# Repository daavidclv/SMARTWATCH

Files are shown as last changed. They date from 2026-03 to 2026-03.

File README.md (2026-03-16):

# HWIoT

Esta rama incluye el contenido relacionado con la electrónica del proytecto como esquemas eléctricos, componentes, etc

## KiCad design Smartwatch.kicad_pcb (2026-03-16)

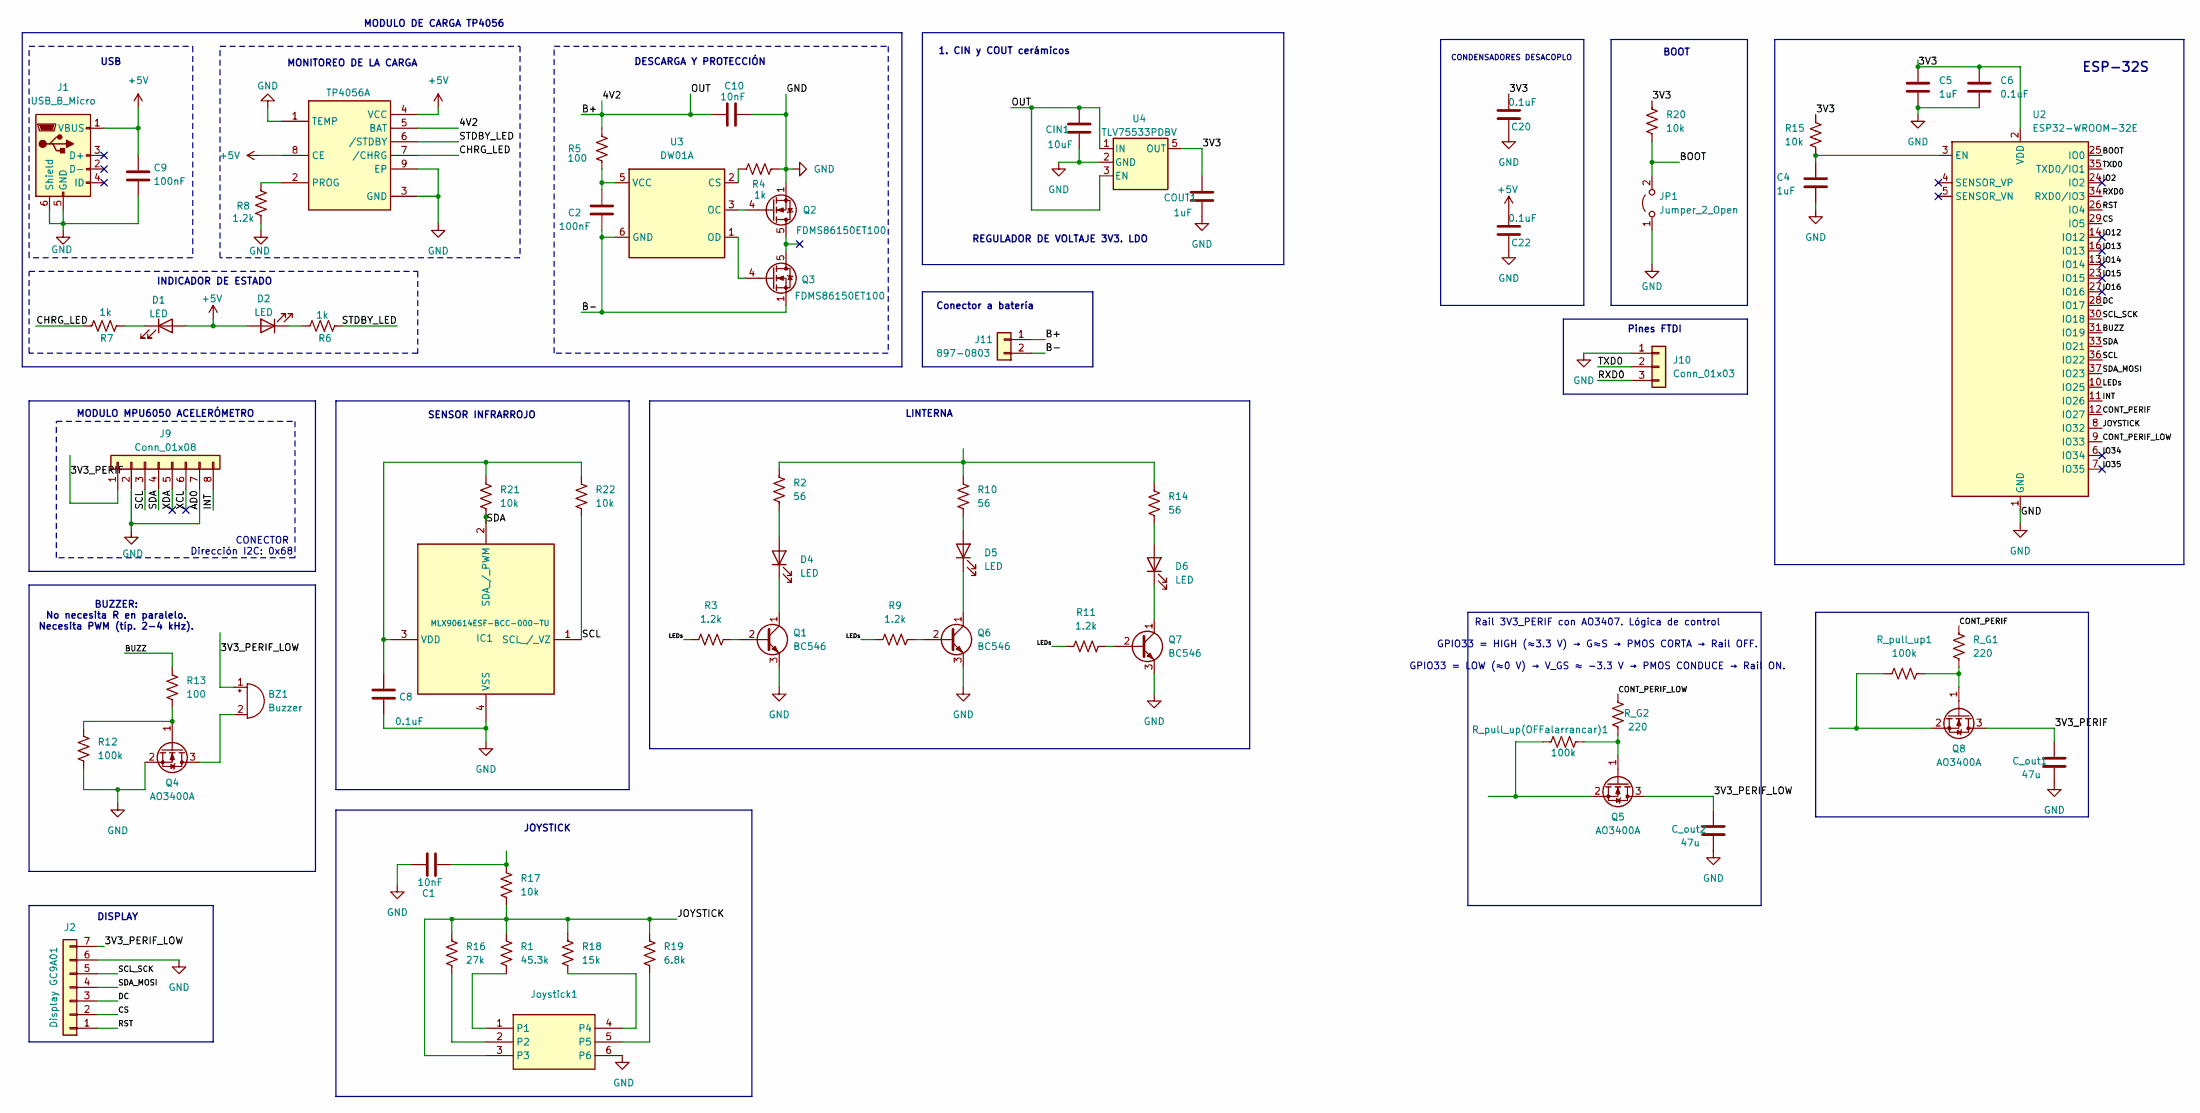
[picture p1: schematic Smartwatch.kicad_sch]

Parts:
BZ1: Buzzer; Buzzer_15x7.5RM7.6
C1, C10: 10nF; C_0805_2012Metric
C2, C9: 100nF; C_0805_2012Metric
C4, C5: 1uF; C_0805_2012Metric
C6, C8, C20, C22: 0.1uF; C_0805_2012Metric
CIN1: 10uF; CP_Radial_D4.0mm_P2.00mm
COUT1: 1uF; CP_Radial_D4.0mm_P2.00mm
C_out1, C_out2: 47u; C_0805_2012Metric
D1, D2, D4, D5, D6: LED; LED_D3.0mm
IC1: MLX90614ESF-BCC-000-TU; MLX90614ESFBCC000TU; Mouser Part Number 482-90614ESFBCC000TU
J1: USB_B_Micro; USB_Mini-B_Wuerth_65100516121_Horizontal
J2: Display GC9A01; PinHeader_1x07_P2.54mm_Vertical
J9: Conn_01x08; PinHeader_1x08_P2.54mm_Vertical
J10: Conn_01x03; PinHeader_1x03_P2.54mm_Vertical
J11: 897-0803; JST_XH_S2B-XH-A_1x02_P2.50mm_Horizontal
JP1: Jumper_2_Open; PinHeader_1x02_P2.54mm_Vertical
Joystick1: Joystick
Q1, Q6, Q7: BC546; TO-92_Inline
Q2, Q3: FDMS86150ET100; TDSON-8-1
Q4, Q5, Q8: AO3400A; SOT-23
R1: 45.3k; R_0805_2012Metric
R2, R10, R14: 56; R_0805_2012Metric
R3, R8, R9, R11: 1.2k; R_0805_2012Metric
R4, R6, R7: 1k; R_0805_2012Metric
R5, R13: 100; R_0805_2012Metric
R12: 100k; R_0805_2012Metric
R15, R17, R20, R21, R22: 10k; R_0805_2012Metric
R16: 27k; R_0805_2012Metric
R18: 15k; R_0805_2012Metric
R19: 6.8k; R_0805_2012Metric
R_G1, R_G2: 220; R_0805_2012Metric
R_pull_up1: 100k; R_0805_2012Metric
R_pull_up(OFFalarrancar)1: 100k; R_0805_2012Metric
TP4056: 4538; TP4056-42-ESOP8_TPW
U2: ESP32-WROOM-32E; ESP32-WROOM-32D
U3: DW01A; SOT-23-6
U4: TLV75533PDBV; SOT-23-5

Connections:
+5V: C9.1, C22.1, D1.2 (A), D2.2 (A), J1.1 (VBUS), TP4056.4 (VCC), TP4056.8 (CE)
/3V3: C5.1, C6.1, C20.1, COUT1.1, R15.1, R20.1, U2.2 (VDD), U4.5 (OUT)
/3V3_PERIF: C_out1.1, J9.1, Q8.3 (D)
/3V3_PERIF_LOW: BZ1.1 (+), C_out2.1, J2.7, Q5.3 (D)
/4V2: C10.1, CIN1.1, J11.1 (Puente1), R5.2, TP4056.5 (BAT), U4.1 (IN), U4.3 (EN)
/B-: C2.1, J11.2 (Puente2), Q3.1 (S), Q3.2 (S), Q3.3 (S), U3.6 (GND)
/BOOT: JP1.2 (B), R20.2, U2.25 (IO0)
/BUZZ: R13.2, U2.31 (IO19)
/CHRG_LED: R7.2, TP4056.7 (/CHRG)
/CONT_PERIF: R_G1.2, U2.12 (IO27)
/CONT_PERIF_LOW: R_G2.2, U2.9 (IO33)
/CS: J2.2, U2.29 (IO5)
/DC: J2.3, U2.28 (IO17)
/INT: J9.8, U2.11 (IO26)
/IO2: U2.24 (IO2)
/IO12: U2.14 (IO12)
/IO13: U2.16 (IO13)
/IO14: U2.13 (IO14)
/IO15: U2.23 (IO15)
/IO16: U2.27 (IO16)
/IO34: U2.6 (IO34)
/IO35: U2.7 (IO35)
/JOYSTICK: Joystick1.3, R1.1, R16.2, R17.1, R18.2, R19.2, U2.8 (IO32)
/LEDs: R3.1, R9.1, R11.1, U2.10 (IO25)
/RST: J2.1, U2.26 (IO4)
/RXD0: J10.3, U2.34 (RXD0/IO3)
/SCL: IC1.1 (SCL_/_VZ), J9.3, R22.2, U2.36 (IO22)
/SCL_SCK: J2.5, U2.30 (IO18)
/SDA: IC1.2 (SDA_/_PWM), J9.4, R21.1, U2.33 (IO21)
/SDA_MOSI: J2.4, U2.37 (IO23)
/STDBY_LED: R6.1, TP4056.6 (/STDBY)
/TXD0: J10.2, U2.35 (TXD0/IO1)
/XCL: J9.6
/XDA: J9.5
GND: C1.2, C4.2, C5.2, C6.2, C8.2, C9.2, C10.2, C20.2, C22.2, CIN1.2, COUT1.2, C_out1.2, C_out2.2, IC1.4 (VSS), J1.5 (GND), J1.6 (Shield), J2.6, J9.2, J9.7, J10.1, JP1.1 (A), Joystick1.6, Q1.3 (E), Q2.1 (S), Q2.2 (S), Q2.3 (S), Q4.2 (S), Q6.3 (E), Q7.3 (E), R4.2, R8.1, R12.1, TP4056.1 (TEMP), TP4056.3 (GND), TP4056.9 (EP), U2.1 (GND), U2.15 (GND), U2.38 (GND), U2.39 (GND), U4.2 (GND)
unnamed: BZ1.2 (-), Q4.3 (D)
unnamed: C1.1, R17.2
unnamed: D1.1 (K), R7.1
unnamed: D2.1 (K), R6.2
unnamed: D4.2 (A), R2.2
unnamed: D4.1 (K), Q1.1 (C)
unnamed: D5.2 (A), R10.2
unnamed: D5.1 (K), Q6.1 (C)
unnamed: D6.2 (A), R14.2
unnamed: D6.1 (K), Q7.1 (C)
unnamed: C8.1, IC1.3 (VDD), R21.2, R22.1
unnamed: Joystick1.1, R1.2
unnamed: Joystick1.2, R16.1
unnamed: Joystick1.4, R18.1
unnamed: Joystick1.5, R19.1
unnamed: Q1.2 (B), R3.2
unnamed: Q2.4 (G), U3.3 (OC)
unnamed: Q3.4 (G), U3.1 (OD)
unnamed: Q4.1 (G), R12.2, R13.1
unnamed 54: Q5.1 (G), R_G2.1, R_pull_up(OFFalarrancar)1.2; also elsewhere on the board
unnamed 55: Q5.2 (S), R_pull_up(OFFalarrancar)1.1; also elsewhere on the board
unnamed: Q6.2 (B), R9.2
unnamed: Q7.2 (B), R11.2
unnamed 58: Q8.1 (G), R_G1.1, R_pull_up1.2; also elsewhere on the board
unnamed 59: Q8.2 (S), R_pull_up1.1; also elsewhere on the board
unnamed: R2.1, R10.1, R14.1
unnamed: R8.2, TP4056.2 (PROG)
unnamed: C4.1, R15.2, U2.3 (EN)
unnamed: R4.1, U3.2 (CS)
unnamed: C2.2, R5.1, U3.5 (VCC)

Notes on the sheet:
CONECTOR
MODULO MPU6050 ACELERÓMETRO
DESCARGA Y PROTECCIÓN
USB
CONDENSADORES DESACOPLO
ESP-32S
Pines FTDI
SENSOR INFRARROJO
REGULADOR DE VOLTAJE 3V3. LDO
MODULO DE CARGA TP4056
Dirección I2C: 0x68
1. CIN y COUT cerámicos
LINTERNA
JOYSTICK
BUZZER: No necesita R en paralelo. Necesita PWM (típ. 2-4 kHz).
MONITOREO DE LA CARGA
DISPLAY
Rail 3V3_PERIF con AO3407. Lógica de control GPIO33 = HIGH (≈3.3 V) → G≈S → PMOS CORTA → Rail OFF. GPIO33 = LOW (≈0 V) → V_GS ≈ −3.3 V → PMOS CONDUCE → Rail ON.
Conector a batería
INDICADOR DE ESTADO
BOOT

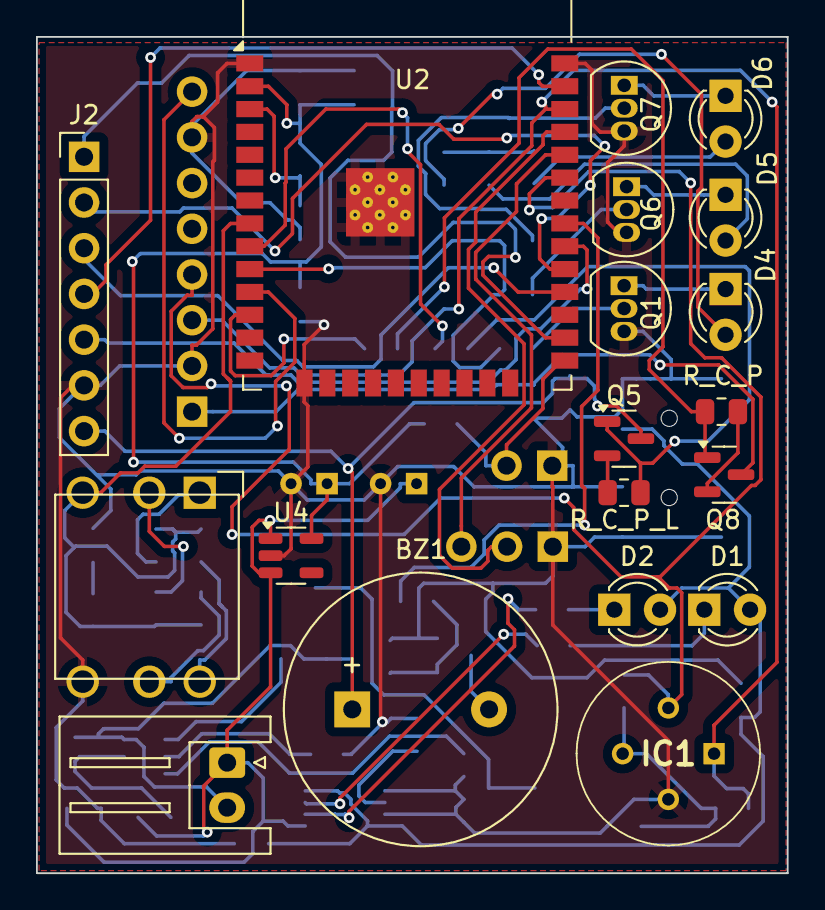
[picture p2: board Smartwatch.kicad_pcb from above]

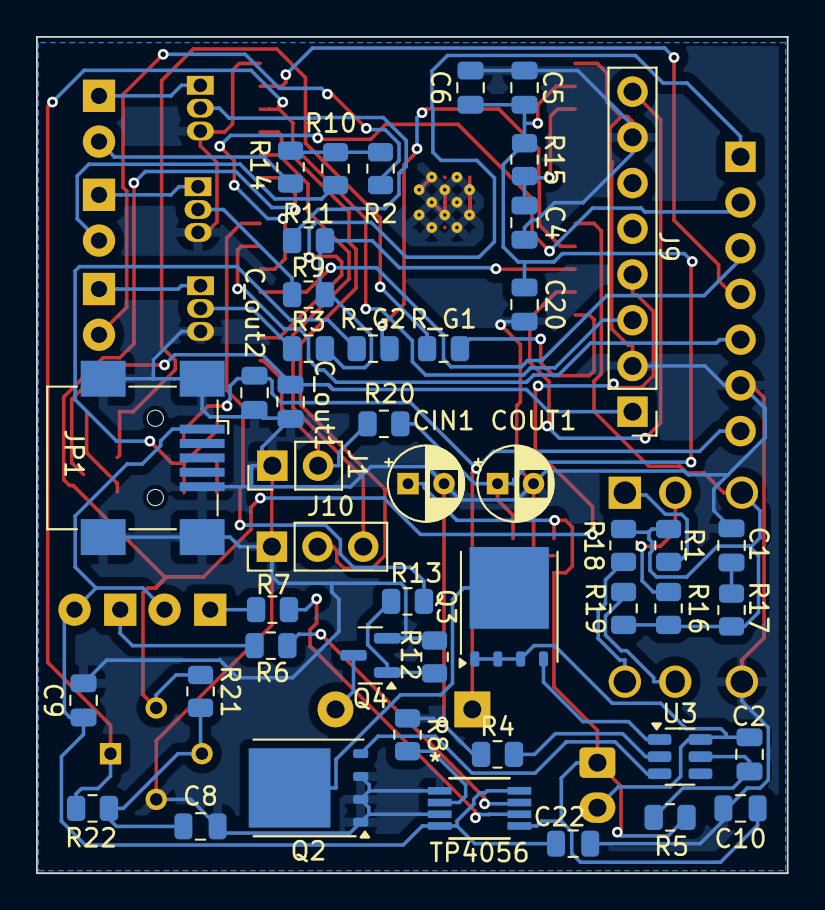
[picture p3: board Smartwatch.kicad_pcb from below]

Board: 2 copper layers, 41.7 x 46.5 mm, 66 parts (47 on the bottom side), 55 nets.

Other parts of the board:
R_C_P: 100k; R_0805_2012Metric
R_C_P_L: 100k; R_0805_2012Metric

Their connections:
unnamed 54: R_C_P_L.2; also elsewhere on the board
unnamed 55: R_C_P_L.1; also elsewhere on the board
unnamed 58: R_C_P.2; also elsewhere on the board
unnamed 59: R_C_P.1; also elsewhere on the board
